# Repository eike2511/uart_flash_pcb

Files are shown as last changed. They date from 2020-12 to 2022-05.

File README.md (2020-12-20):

# UART flash PCB

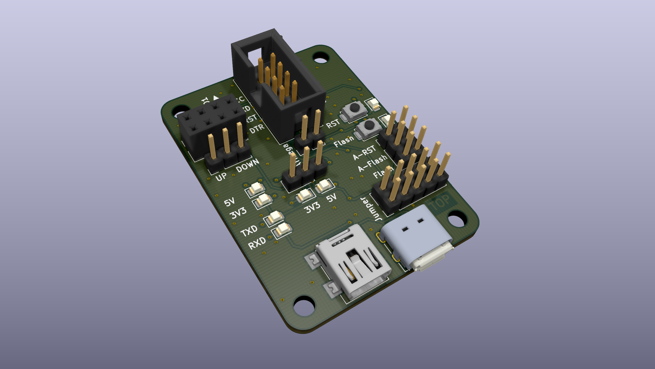
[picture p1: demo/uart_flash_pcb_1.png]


## Features:
- flash µC over UART
	- ESP8266
	- ESP32
	- ATMEGA
	- intigrated slot for ESP8266-01
- intigrated RST and flash button
	- with LEDs and labelling
	- jumper for manual and auto mode
- Reverse polarity protected pin tray
- Three different USB sockets
	- mini USB B
	- micro USB B
	- USB C
- Vcc = 5V  or 3.3V 
	- with LEDs and labelling
	- jumper for selection
	- 5V from USB Bus
	- 3.3V from additional linear regulator in connection with internal regulator of the FT232,  with up to 800mA
- LEDs at TXD and RXD for visual control of the UART connection

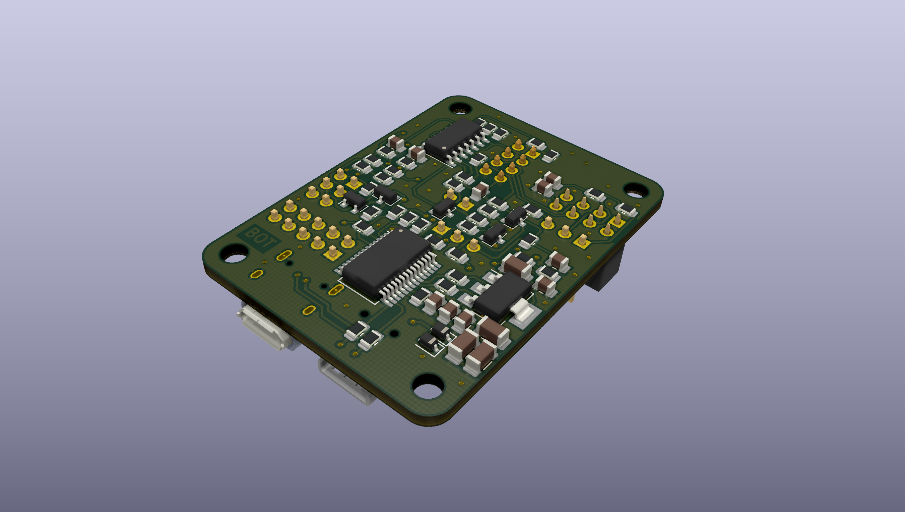
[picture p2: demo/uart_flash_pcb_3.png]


## Hardware:
Gerber and drilling data are in the repository. [Component placement](./uart_flash_pcb_ibom.html)

## Software:
No stand-alone software is needed. Use esptool.py or e.g. VS Code for programming.

## Usage:
1. Connect USB
2. Connect the correct jumpers for 5V or 3.3V
3. Connect the jumpers for auto-flash and auto-RST or use the button
4. Connect the device to be flashed or plug in an ESP-01
5. be save the TXD and RXD are crossed

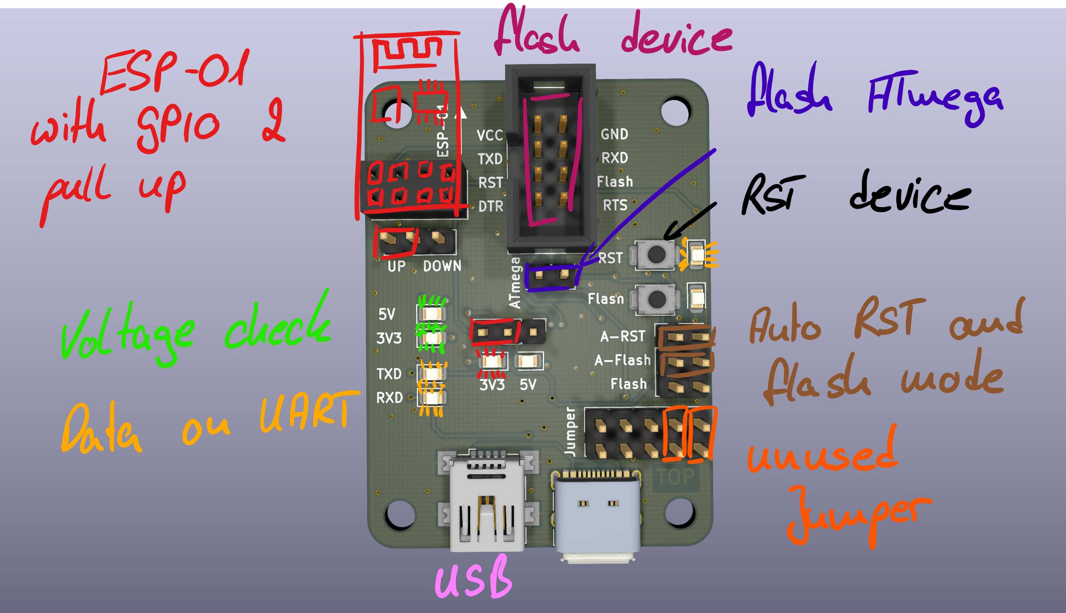
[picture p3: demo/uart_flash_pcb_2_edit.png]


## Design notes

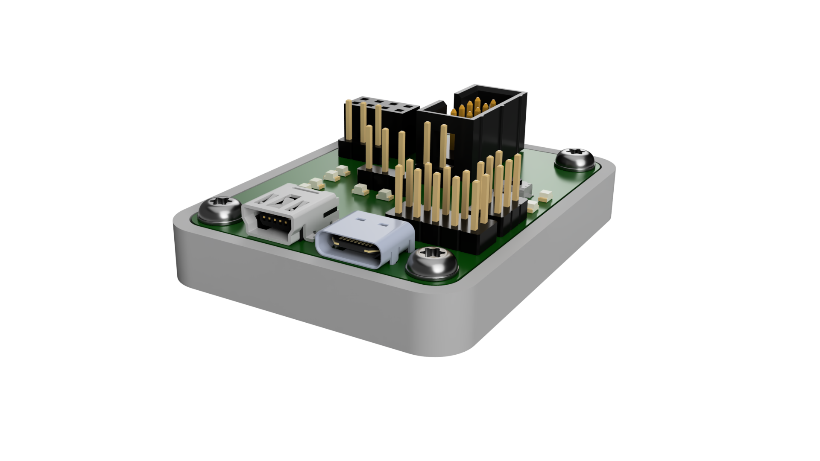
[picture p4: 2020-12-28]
demo/uart_flash_pcb_render_2.png

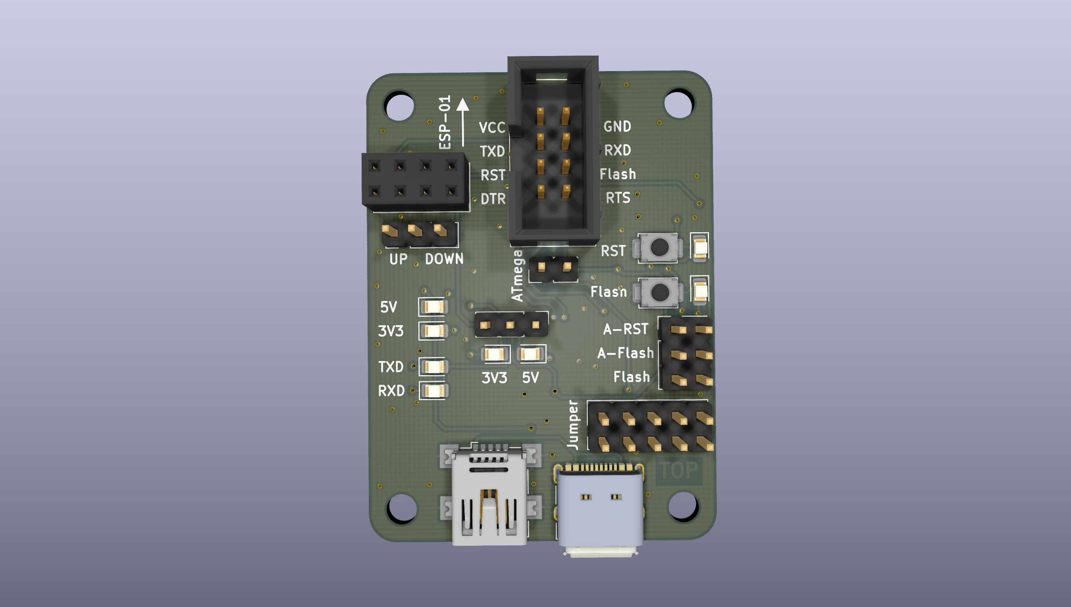
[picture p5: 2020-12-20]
demo/uart_flash_pcb_2.png

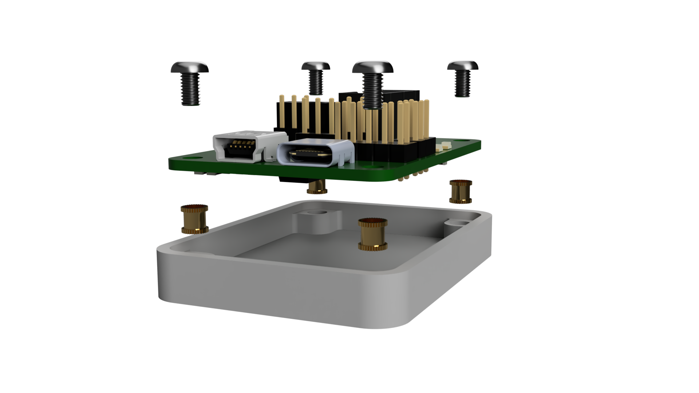
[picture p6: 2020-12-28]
demo/uart_flash_pcb_explosion_graphic_2.png

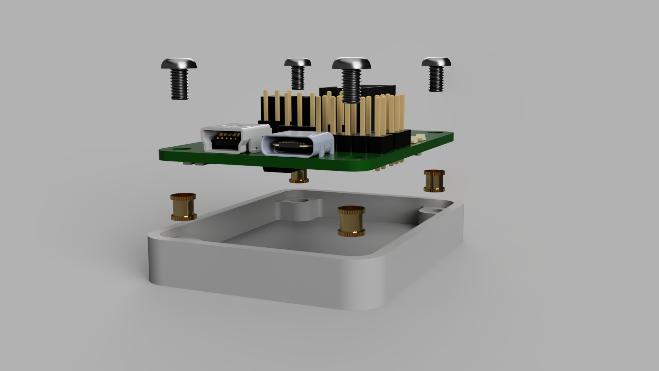
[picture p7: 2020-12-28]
demo/uart_flash_pcb_explosion_graphic_1.png

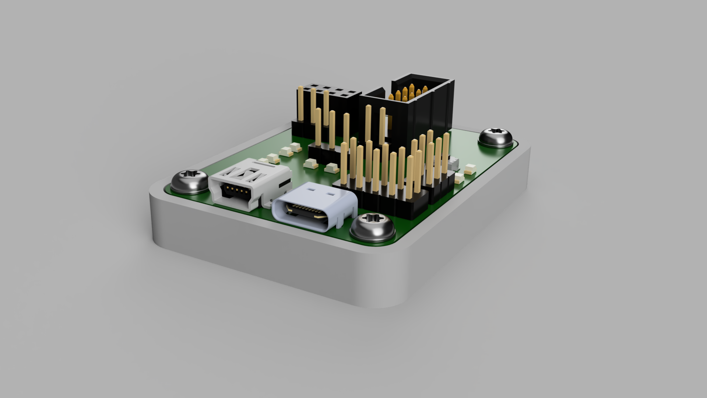
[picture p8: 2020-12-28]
demo/uart_flash_pcb_render_1.png

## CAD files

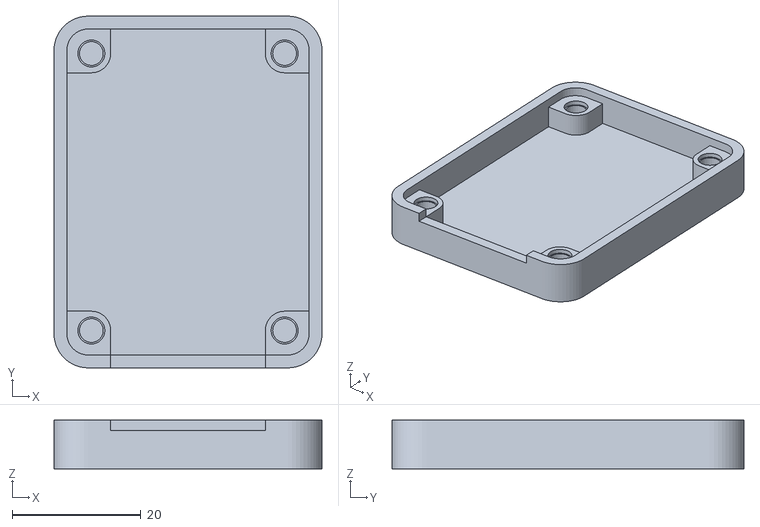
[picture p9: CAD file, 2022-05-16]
uart_flash_pcb_3d_print_case_v2.stl
41.6 x 54.6 x 7.60

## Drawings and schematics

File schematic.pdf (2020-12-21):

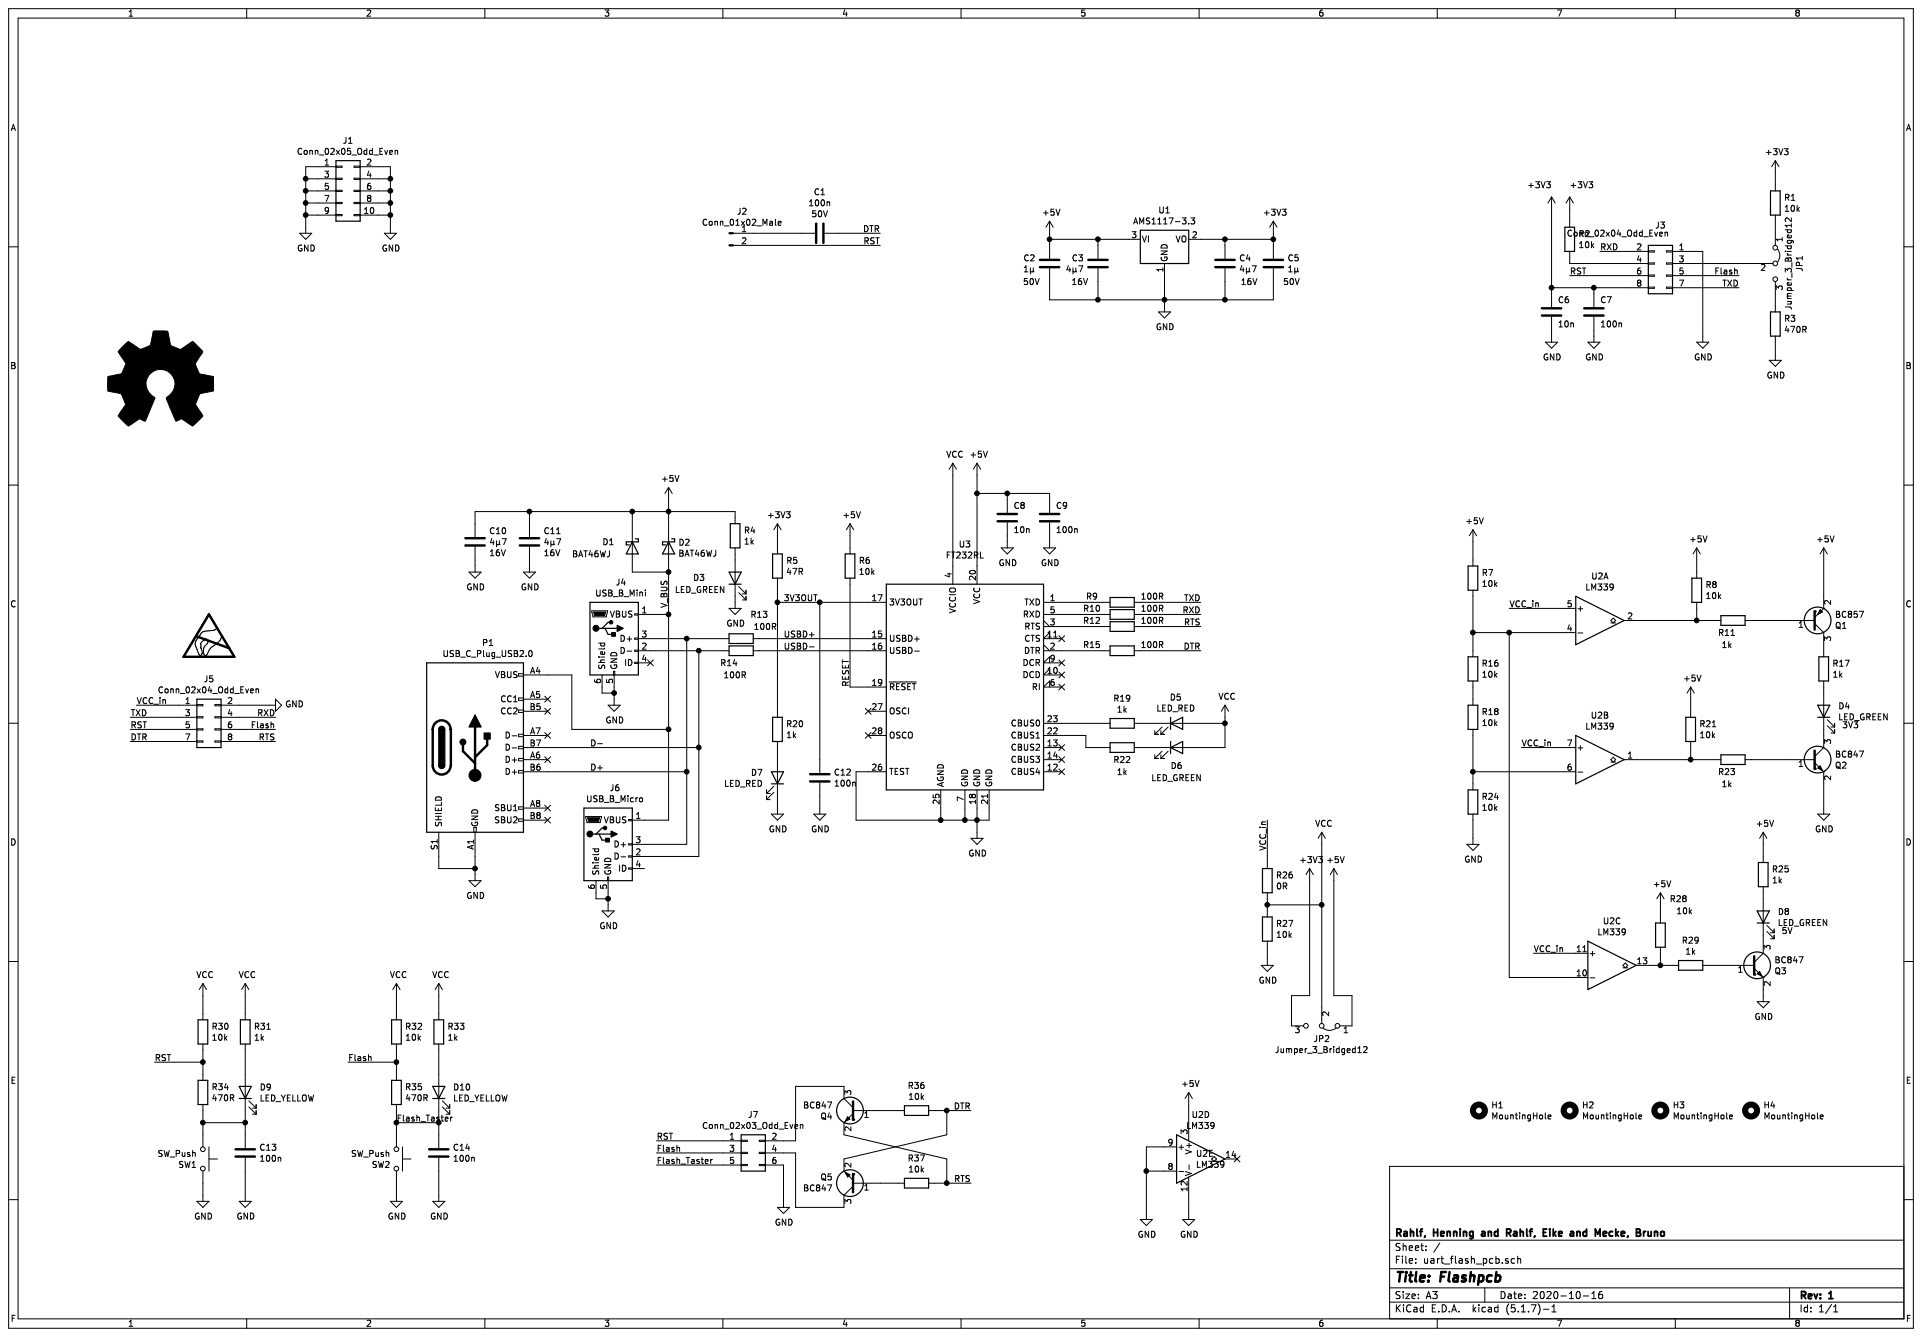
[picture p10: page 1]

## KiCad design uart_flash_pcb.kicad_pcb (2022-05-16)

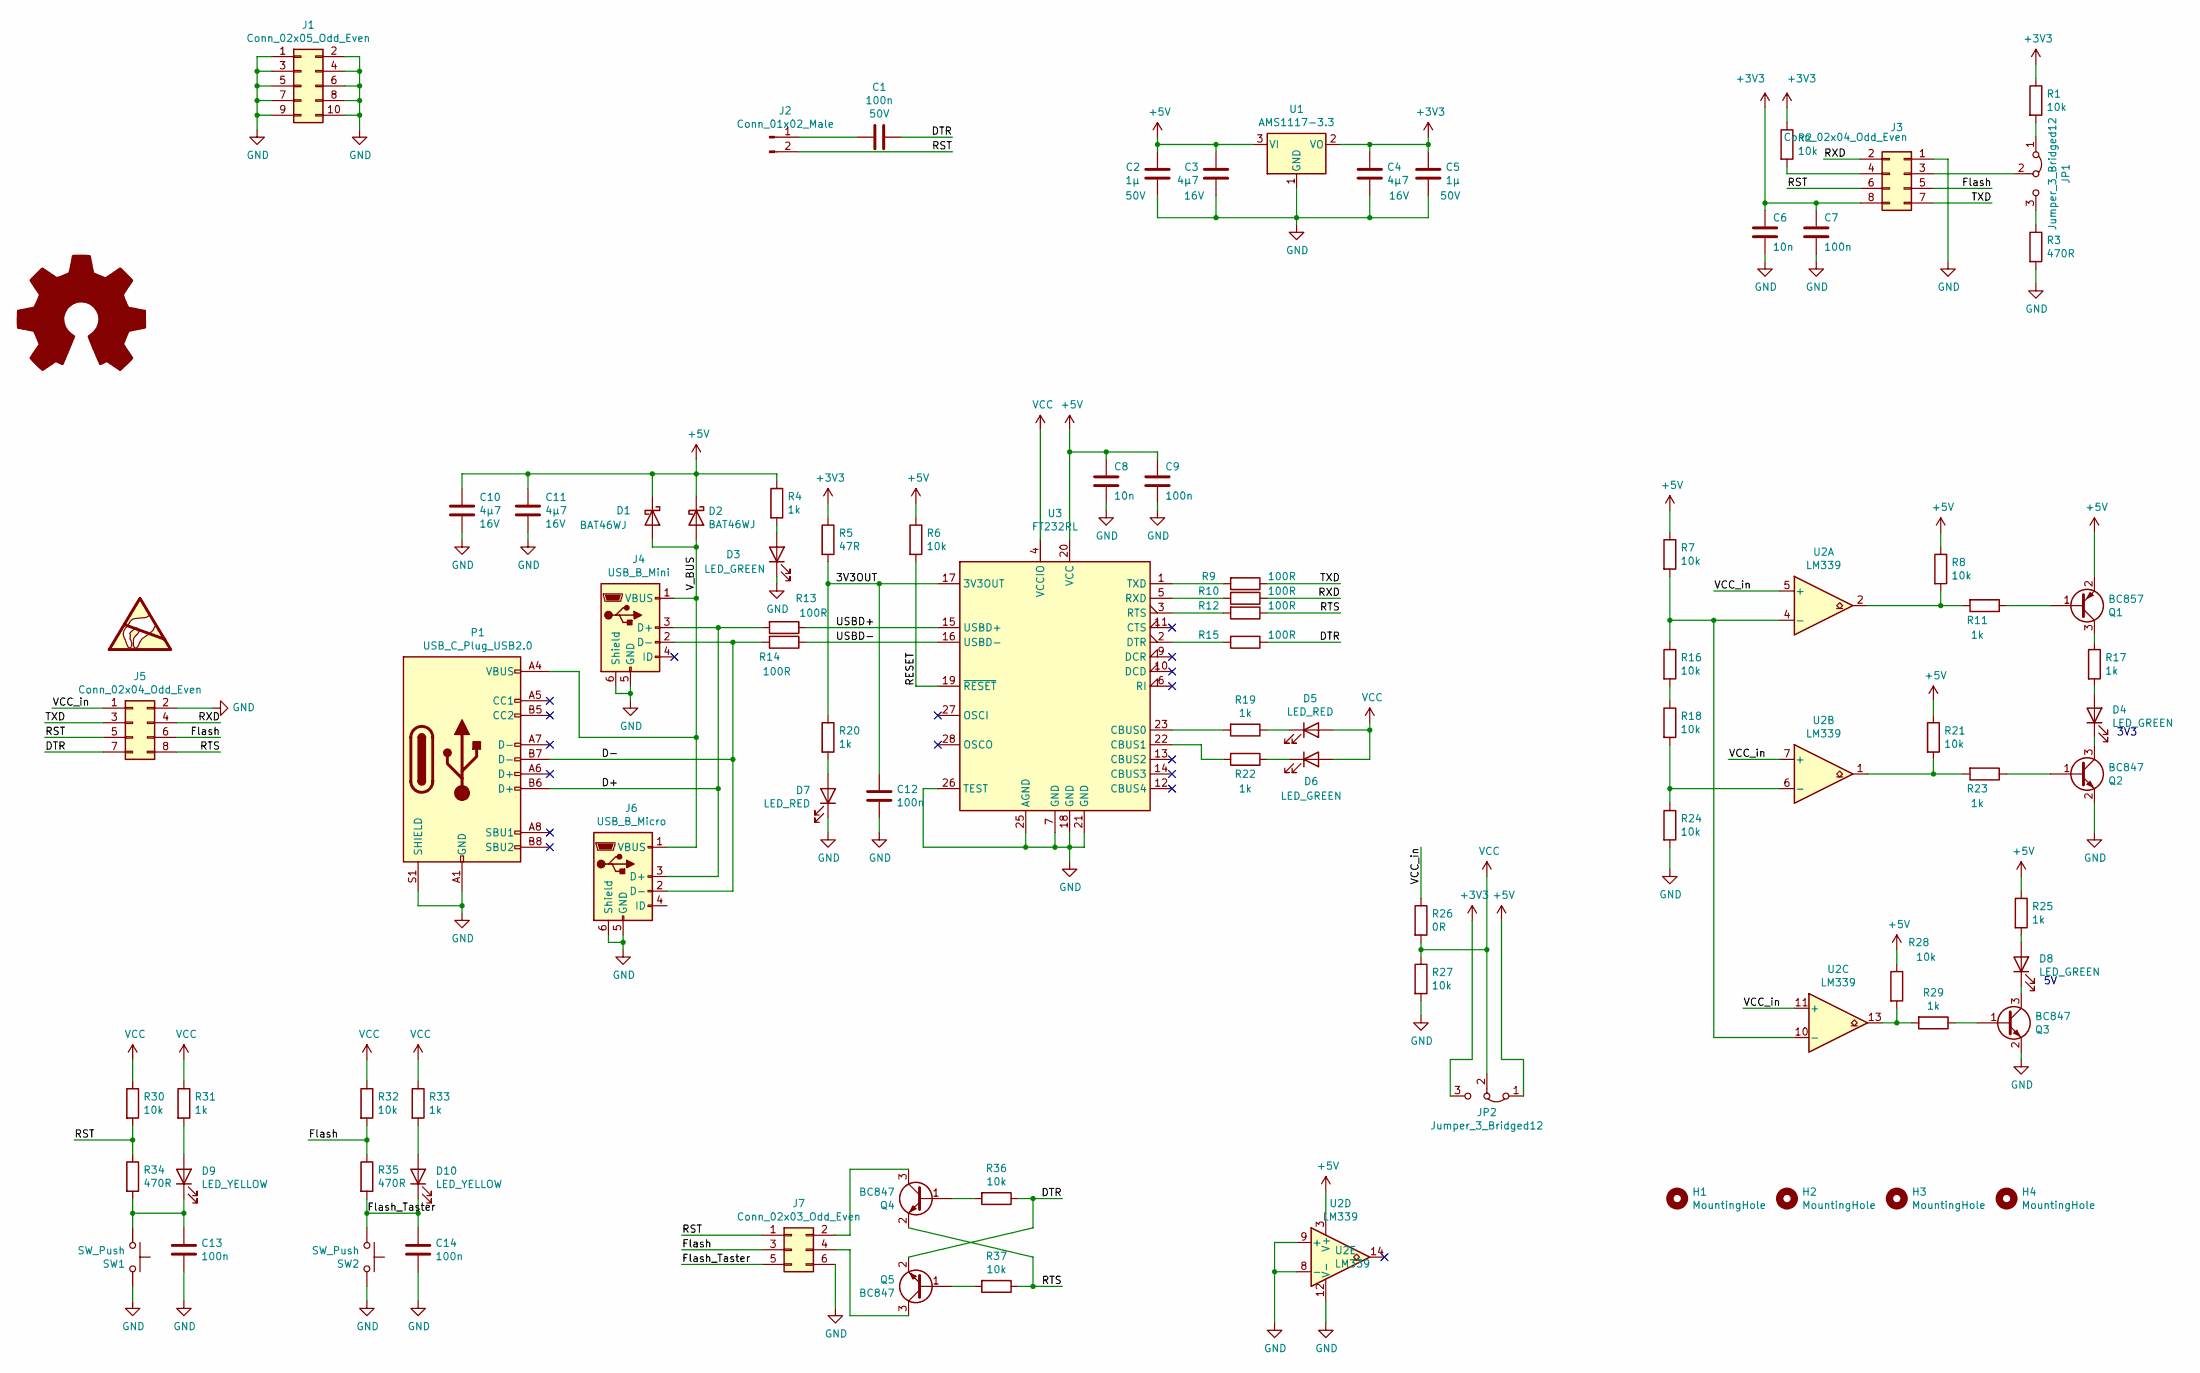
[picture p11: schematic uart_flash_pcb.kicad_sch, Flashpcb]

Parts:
C1, C7, C9, C12, C13, C14: 100n; C_0805_2012Metric
C2, C5: 1µ; C_0805_2012Metric
C3, C4, C10, C11: 4µ7; C_1206_3216Metric
C6, C8: 10n; C_0805_2012Metric
D1, D2: BAT46WJ; D_SOD-323
D3, D4, D6, D8: LED_GREEN; LED_0805_2012Metric
D5, D7: LED_RED; LED_0805_2012Metric
D9, D10: LED_YELLOW; LED_0805_2012Metric
H1, H2, H3, H4: MountingHole; MountingHole_3.2mm_M3
J1: Conn_02x05_Odd_Even; PinHeader_2x05_P2.54mm_Vertical
J2: Conn_01x02_Male; PinHeader_1x02_P2.54mm_Vertical
J3: Conn_02x04_Odd_Even; PinSocket_2x04_P2.54mm_Vertical
J4: USB_B_Mini; USB_Mini-B_Wuerth_65100516121_Horizontal
J5: Conn_02x04_Odd_Even; PinHeader_2x04_P2.54mm_Vertical
J6: USB_B_Micro; USB_Micro-B_Molex_47346-0001
J7: Conn_02x03_Odd_Even; PinHeader_2x03_P2.54mm_Vertical
JP1, JP2: Jumper_3_Bridged12; PinHeader_1x03_P2.54mm_Vertical
P1: USB_C_Plug_USB2.0; USB_C_Receptacle_XKB_U262-16XN-4BVC11
Q1: BC857; SOT-23
Q2, Q3, Q4, Q5: BC847; SOT-23
R1, R2, R6, R7, R8, R16, R18, R21, R24, R27, R28, R30, R32, R36, R37: 10k; R_0805_2012Metric
R3, R34, R35: 470R; R_0805_2012Metric
R4, R11, R17, R19, R20, R22, R23, R25, R29, R31, R33: 1k; R_0805_2012Metric
R5: 47R; R_0805_2012Metric
R9, R10, R12, R13, R14, R15: 100R; R_0805_2012Metric
R26: 0R; R_0805_2012Metric
SW1, SW2: SW_Push; SW_Push_SPST_4x3x2
U1: AMS1117-3.3; SOT-223-3_TabPin2
U2: LM339; SOIC-14_3.9x8.7mm_P1.27mm
U3: FT232RL; SSOP-28_5.3x10.2mm_P0.65mm

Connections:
+3V3: C4.1, C5.1, C6.1, C7.1, J3.8, JP2.3 (B), R1.1, R2.1, R5.1, U1.2 (VO)
+5V: C2.1, C3.1, C8.1, C9.1, C10.1, C11.1, D1.1 (K), D2.1 (K), JP2.1 (A), Q1.2 (E), R4.1, R6.1, R7.1, R8.1, R21.1, R25.1, R28.1, U1.3 (VI), U2.3 (V+), U3.20 (VCC)
/3V3OUT: C12.1, R5.2, R20.1, U3.17 (3V3OUT)
/D+: J4.3 (D+), J6.3 (D+), P1.B6 (D+), R13.2
/D-: J4.2 (D-), J6.2 (D-), P1.B7 (D-), R14.2
/DTR: C1.1, J5.7, Q5.2 (E), R15.1, R36.1
/Flash: J3.5, J5.6, J7.3, R32.2, R35.1
/Flash_Taster: C14.1, D10.1 (K), J7.5, R35.2, SW2.1
/RESET: R6.2, U3.19 (~RESET)
/RST: J2.2, J3.6, J5.5, J7.1, R30.2, R34.1
/RTS: J5.8, Q4.2 (E), R12.1, R37.1
/RXD: J3.2, J5.4, R10.1
/TXD: J3.7, J5.3, R9.1
/USBD+: R13.1, U3.15 (USBD+)
/USBD-: R14.1, U3.16 (USBD-)
/VCC_in: J5.1, R26.1, U2.5 (+), U2.7 (+), U2.11 (+)
/V_BUS: D1.2 (A), D2.2 (A), J4.1 (VBUS), J6.1 (VBUS), P1.A4 (VBUS), P1.A9 (VBUS), P1.B4 (VBUS), P1.B9 (VBUS)
GND: C2.2, C3.2, C4.2, C5.2, C6.2, C7.2, C8.2, C9.2, C10.2, C11.2, C12.2, C13.2, C14.2, D3.1 (K), D7.1 (K), J1.1, J1.2, J1.3, J1.4, J1.5, J1.6, J1.7, J1.8, J1.9, J1.10, J3.1, J4.5 (GND), J4.6 (Shield), J5.2, J6.5 (GND), J6.6 (Shield), J7.6, P1.A1 (GND), P1.A12 (GND), P1.B1 (GND), P1.B12 (GND), P1.S1 (SHIELD), Q2.2 (E), Q3.2 (E), R3.2, R24.2, R27.2, SW1.2, SW2.2, U1.1 (GND), U2.8 (-), U2.9 (+), U2.12 (V-), U3.7 (GND), U3.18 (GND), U3.21 (GND), U3.25 (AGND), U3.26 (TEST)
unnamed: C1.2, J2.1
unnamed: C13.1, D9.1 (K), R34.2, SW1.1
unnamed: D3.2 (A), R4.2
unnamed: D4.1 (K), Q2.3 (C)
unnamed: D4.2 (A), R17.2
unnamed: D5.1 (K), R19.1
unnamed: D6.1 (K), R22.1
unnamed: D7.2 (A), R20.2
unnamed: D8.1 (K), Q3.3 (C)
unnamed: D8.2 (A), R25.2
unnamed: D9.2 (A), R31.2
unnamed: D10.2 (A), R33.2
unnamed: J3.3, JP1.2 (C)
unnamed: J3.4, R2.2
unnamed: J7.2, Q4.3 (C)
unnamed: J7.4, Q5.3 (C)
unnamed: JP1.1 (A), R1.2
unnamed: JP1.3 (B), R3.1
unnamed: Q1.1 (B), R11.1
unnamed: Q1.3 (C), R17.1
unnamed: Q2.1 (B), R23.1
unnamed: Q3.1 (B), R29.1
unnamed: Q4.1 (B), R36.2
unnamed: Q5.1 (B), R37.2
unnamed: R9.2, U3.1 (TXD)
unnamed: R10.2, U3.5 (RXD)
unnamed: R8.2, R11.2, U2.2
unnamed: R12.2, U3.3 (RTS)
unnamed: R15.2, U3.2 (DTR)
unnamed: R7.2, R16.1, U2.4 (-), U2.10 (-)
unnamed: R16.2, R18.1
unnamed: R18.2, R24.1, U2.6 (-)
unnamed: R19.2, U3.23 (CBUS0)
unnamed: R21.2, R23.2, U2.1
unnamed: R22.2, U3.22 (CBUS1)
unnamed: R28.2, R29.2, U2.13
VCC: D5.2 (A), D6.2 (A), JP2.2 (C), R26.2, R27.1, R30.1, R31.1, R32.1, R33.1, U3.4 (VCCIO)

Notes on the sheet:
3V3

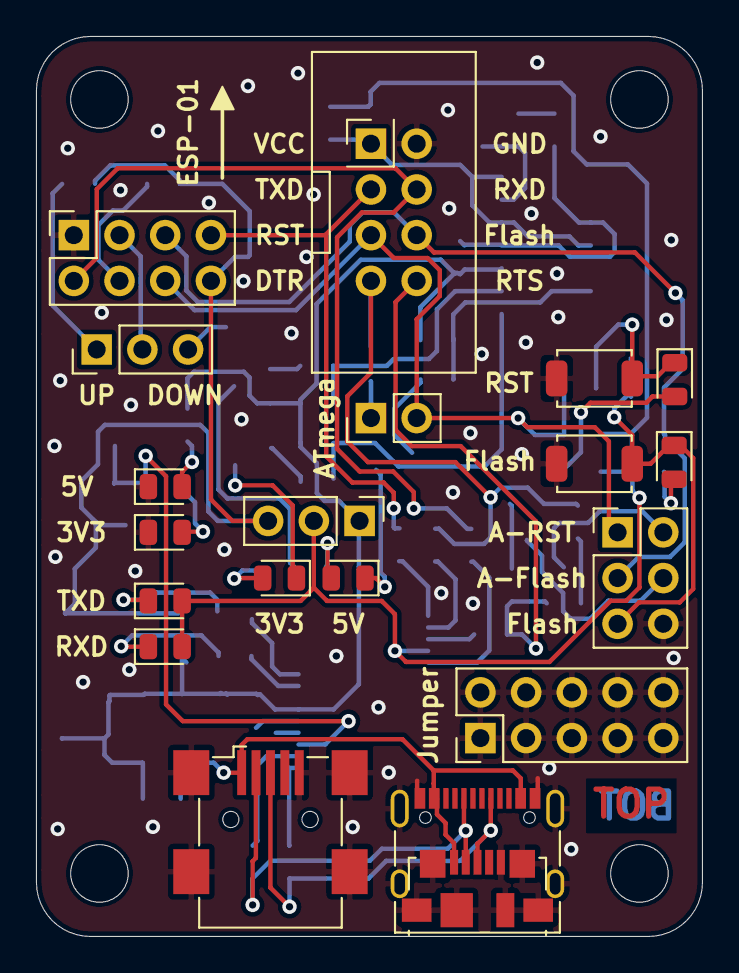
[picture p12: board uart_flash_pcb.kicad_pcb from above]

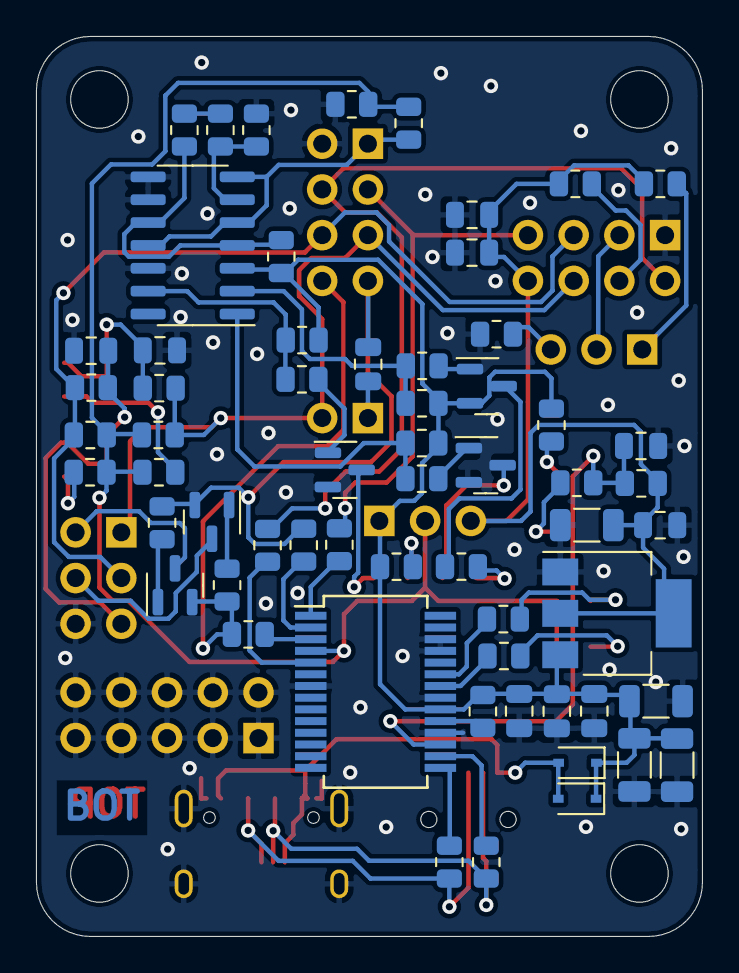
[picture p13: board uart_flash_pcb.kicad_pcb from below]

Board: 2 copper layers, 37.0 x 50.0 mm, 85 parts (61 on the bottom side), 55 nets.

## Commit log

2020-12-21 Update footprints because of library update
    [uart_flash_pcb.kicad_pcb]
2020-12-21 Added schematic as PDF
2020-12-28 Added 3D models and rendering pictures
    [uart_flash_pcb_3d_print_case.stl]
2022-05-16 Update 3D printing case
    [uart_flash_pcb_3d_print_case.stl, uart_flash_pcb_3d_print_case_v2.stl]
2022-05-16 Update to KiCad v6
    [uart_flash_pcb.kicad_pcb, uart_flash_pcb.kicad_sch, uart_flash_pcb.sch]
